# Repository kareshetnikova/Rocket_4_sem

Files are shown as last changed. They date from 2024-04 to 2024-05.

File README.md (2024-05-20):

# Физтех.Ship
Ссылка на телеграм канал - https://t.me/phystechShip, там есть все фото и видео

### Цель проекта

Разработка борткомпьютера с функцией измерения телеметрии и автоматическим выпуском парашюта.

### Борткомпьютер

1. Акселерометр+гироскоп+высотомер+компас - **GY-87**
3. Плата - Arduino nano/**Raspberry Pi Pico**
5. **SD-карта - модуль для arduino**
6. GPS - **NEO 7M**
7. GSM - **SIM800L**
8. Пищалка - **SFM-27/DC3-24V**
9. Система выброса парашюта - **механическая** или с использованием запала и вышибного заряда
10. Тумблер
11. Светодиоды индикации
12. Питание - **Li-Ion 16340 3.7V** 

### Распределение задач 

Диана:
1. Расчет центров масс и давления
2. Расчеты параметров обтекателя и стабилизаторов
3. Моделирование и создание обтекателя и стабилизаторов
4. Корпус для электроники
6. Система спасения (парашют + система его выпуска)

Ксюша:
1. Электроника борткомпьютера
2. Сборка

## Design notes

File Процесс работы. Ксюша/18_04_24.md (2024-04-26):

Запустила rp2040 (pico) из arduino ide. Мигает светодиодами, в порт данные выводит. 
BMP180 пока подключить не получилось. Но плата прикольная, берем

Подключала mpu по i2c. SDA, SCL = GP4, GP5. Непонятно, как их определять, на распиновке другие пины

Данные с mpu выводит корректно, главное - чтоб в коде не было LED_PIN = 13 и прочего.

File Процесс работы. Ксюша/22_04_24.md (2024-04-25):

Проверила UART на малинке, работает с 2 пар пинов с NEO7M.

GPS тройка модуль тоже работает.

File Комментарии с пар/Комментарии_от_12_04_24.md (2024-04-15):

### Комментарии от 12.04.2024

1. Можно использовать акум типа https://www.chipdip.ru/product/robiton-lp302030-3.7
2. Sim800l  питать от акума, а не от контроллера 
3. Ардуино можно заменить на rp2040 pico, у него 2 UART. Подумать об этом
4. Надо продумать крепление модулей внутри ракеты: корпус из пластика или макетка для пайки

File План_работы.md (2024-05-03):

# План работы 

### **12.04 - 19.04**

*Диана:*
1. Продумать конструкцию (то есть всю механику)
2. Продумать, как располагать модули (в том числе продумать корпус)

*Ксюша:*
1. Полностью продумать принципиальную схему (в том числе систему выпуска парашюта - транзистор, реле - и выбор МК)
2. Протестить все имеющиеся модули и принести

### **19.04 - 26.04**

 Запихнуть все в ракету, проверить работу борткомпьютера 
 
 *26.04: Просрочили, но все под контролем =)*

### **26.04 - 3.05**

Доработка, отладка 

### **3.05 - 10.05**

Доработка, отладка 

### **10.05 - 17.05**

1. Запуск
2. Презентация

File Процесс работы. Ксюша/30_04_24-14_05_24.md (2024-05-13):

**За это время было сделано следующее:**

1. Был добавлен отдельный акум для GSM

2. Был практически дописан код. С GSM после отправки одной смс весь БК может виснуть (иногда он умудряется отправлять больше,
но при этом данные на SD писаться перестают). Без GSM все рабоатает!! Возможное решение проблемы: добавить стабилизатор напряжения 
к акуму для GSM

3. Была сделана световая индикация работы борткомпа с помощью двух светодиодов

4. Было решено использовать два джампера для запуска борткомпа: один - для GSM, второй для всего остального
(при использовании одного акума могут возникать проблемы в работе БК, GSM ОЧЕНЬ капризный)

5. Было решено испытывать борткомп без ракеты, только на парашюте. И с костылями в виде джамперов

6. Была протестирована пищалка - работает))

7. Было решено не делать систему выпуска парашюта - соответственно, не прогать серву

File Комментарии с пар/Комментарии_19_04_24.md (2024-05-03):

### Комментарии от 19.04.2024

1. Выпуск парашюта: резерв по времени+барометр
2. Сервопривод с резинкой, дверка в корпусе 
3. Отдельный акум для реле, если используем вышибной заряд 
4. Возможно, стоит взять 2 штуки GPS, так как антенна должна быть направлена вверх либо с заданной переодичностью отправлять координату

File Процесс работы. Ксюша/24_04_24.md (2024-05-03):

Есть у ардуино нано особенность - на UART (пины 0 и 1) не должно быть ничего подключено во время прошивки. Про это надо помнить.

Подключала SIM800l:

1. С помощью блока питания из лабы
2. С помощью одной банки 18650

Мигает красный огонек 7-10 раз с частотой 1Гц, потом перерыв 3-4 с, потом снова мигает. На форумах пишут, это значит, что это проблемы с питанием.

Требования на след запуск: 

1. 4.1В/2А нужно для модуля
2. Для теста питания подходит одна банка 18650, запаянная напрямую (на макетке очень не очень работает)
3. Обязательно нужно ставить делитель напряжения на RX линию sim800l
4. У модуля должна быть общая земля с контроллером
5. Модуль очень капризный к току, так что если что-то не так в контакте, он будет сбрасываться
6. Надо попробовать две банки и стабилизатор и еще раз блок питания с симкой
7. Возможно, надо менять местами RX и TX, китайцы иногда путают

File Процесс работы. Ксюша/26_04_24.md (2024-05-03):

Удалось добиться ответа от GSM. Я сформулировала правила работы с ним, чтоб он не капризничал:

1. Вся земля вместе: от ардуины и от модуля 
2. Питание от банки 18650
3. Максимально паяем, где можно
4. Делитель на tx контроллера (на pico ставила 2 и 10 кОм)
5. Используемые пины pico - 0 и 1
6. Сначала отправляем AT, затем устанавливаем текстовый формат AT+CMGF=1, только затем отправляем сообщение

Не получается отправлять сообщения из порта. Там надо использовать char(26), непонятно, как это делать.

Подключила вместе GPS, GSM, MPU, BMP. BMP, GSM работают, GPS еще нет, надо на улицу. Не хватает SD карты, сервы для парашюта и пищалки.

Заставила GSM отправлять координаты!!! 

Посчитала, что GPS для запуска (холодный старт вроде) нужно около минуты, с запасом лучше брать 80с.

Написала код для вывода данных с GPS, MPU, BMP в порт (когда модуль SD будет - все эти данные будут выводиться туда)
и отправки координаты через заданное время после запуска контроллера. Все прошивается работает =)

Надо добавить светодиоды для индикации и предусмотреть это в корпусе.

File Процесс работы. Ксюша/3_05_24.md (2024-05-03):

Подключила SD карту вместе с остальными спаянными компонентами, работает.

Припаяла модуль SD карты.

В коде нужно сначала настроить GSM, потом делать все остальное - GSM может сильно мешать работе контроллера, если не нашел сеть. Например, он тормозит работу порта.

Питание от акума с VSYS (1.8-5.5В на входе), GSM параллельно.

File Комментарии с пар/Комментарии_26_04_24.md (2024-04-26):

Электроника по большей части и корпус должны быть готовы к 3.05.2024, весь проект - к 10.05.2024

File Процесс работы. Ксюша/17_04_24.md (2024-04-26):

Подключала молуль SD-карты. Пробовала 2 рабочие платы ардуино нано. Подключение: sck-->13, mosi-->11, miso-->12, cs-->10. Несколько разных скетчей пробовала.
Две разных SD. В порту ошибка инициализации.

BMP180, MPU6050 вертикальный работают (в том числе вместе). Горизонтальный не работает.
Работают две ардуины с желтым скотчем на разъеме.

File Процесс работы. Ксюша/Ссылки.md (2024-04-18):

Сбор данных с bmp180 и mpu6050 на SD карту: https://github.com/Xavi009/mpu6050_bmp180_arduino

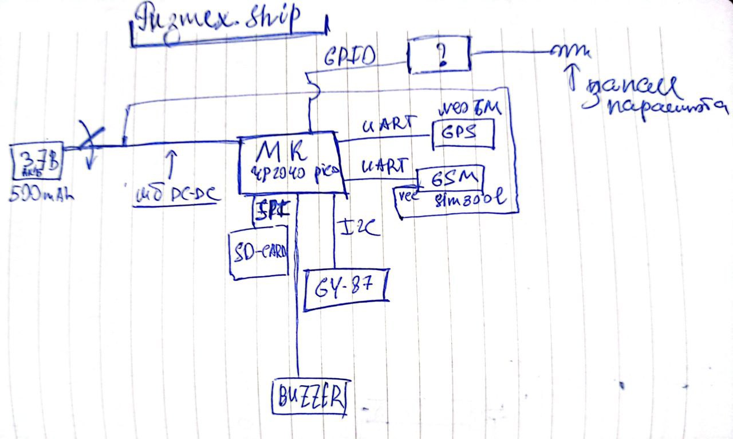
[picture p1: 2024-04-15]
Материалы (схемы, 3D модели и прочее)/Схема_борткомпьютера.jpg

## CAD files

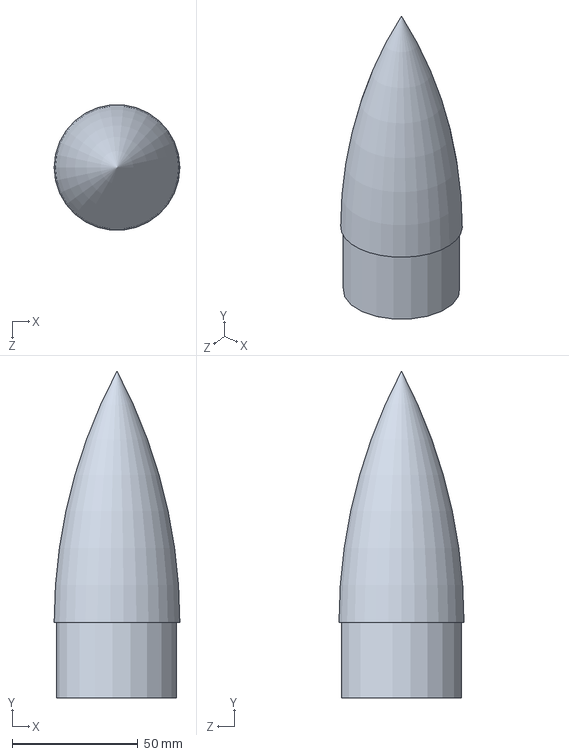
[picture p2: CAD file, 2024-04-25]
Материалы (схемы, 3D модели и прочее)/обтекатель.SLDPRT
50.0 x 130.0 x 49.7 mm

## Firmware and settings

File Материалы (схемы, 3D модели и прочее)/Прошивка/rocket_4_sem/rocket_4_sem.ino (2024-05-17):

#include <TinyGPSPlus.h>
#include <SoftwareSerial.h>
#include "I2Cdev.h"
#include "MPU6050.h"
#include <Adafruit_BMP085.h>
#include <SPI.h>
#include <SD.h>
#include "math.h"


float g = 9.8155;
float R = 8.3145;
float mu = 0.002898;

static const int PIN_CHIP_SELECT = 17;
static const int GPSrx = 9, GPStx = 8, GSMrx = 1, GSMtx = 0;
static const int RED_LED_PIN = 21;
static const int GREEN_LED_PIN = 20;
static const int BUZZER_PIN = 22;

static const uint32_t GPSBaud = 9600;
static const uint32_t SerialBaud = 9600;
static const uint32_t GSMBaud = 9600;
int16_t ax, ay, az;
int16_t gx, gy, gz;
String responseAT = "";  // для хранения ответа от GSM
String _response;
String responseTextMode = ""; 
bool flagGSM = 1; // флаг для отправки сообщений о координатах 
bool FlagGreenLed;
bool FlagRedLed;
bool flagLastSMS = 1;
bool flagHmax = false;
bool flagSentHmax = false;
bool flagMillis = true;

char sms[300];
char sd[300];
char maxHsms[50];
int decLat;
int intLat;
int intLng;
int decLng;
int decT;
int intT;
int P0, p, p1, p2, p3;
float T1, T2, T3;
int intHmax, decHmax;
int timerP1, timerP2, timerP3;



// Настройки работы БК
int CntSMS = 0;
int TotalNumberSMS = 5;
int timerSendCoord;
int PeriodSMS = 1000;
int timeWorkBK = 40000;
int PeriodWriteSD = 100;
int PeriodBuzzer = 1000;
int frequencyBuzzer = 1500;
int timeBuzzer = 1000;



TinyGPSPlus gps;
MPU6050 accelgyro;
Adafruit_BMP085 bmp;

SoftwareSerial ss(GPSrx, GPStx);
SoftwareSerial SIM800(GSMrx, GSMtx);        

int TimeStartGPS;
int timeDisplayInfo;
int TimeGSM;
int timeSD;
int timeStopSD;
int timeRedLed;
int timeGreenLed;
int timeStartGSM;
int timeSendLastCoord;
int timerBuzzer;

void setup() {
  Serial.begin(SerialBaud);
  //while(!Serial);
  
  Wire.begin();

  // свеодиоды
  pinMode(RED_LED_PIN, OUTPUT);  
  pinMode(GREEN_LED_PIN, OUTPUT);  


  //sim800l
  /*timeRedLed = millis();
  FlagRedLed = false;
  SIM800.begin(GSMBaud);
  
  while(SIM800.available() <= 0)
  {
    if (millis() - timeRedLed >= 500)
    {
      Serial.println("Нет подключения к SIM800l");
      digitalWrite(RED_LED_PIN, FlagRedLed);
      digitalWrite(GREEN_LED_PIN, !FlagRedLed); 
      timeRedLed = millis();
      FlagRedLed = !FlagRedLed;
    }
  }*/  
  
  SIM800.begin(GSMBaud);
  
  //ждем 15 сек, чтоб gsm заработал
  int timerStartBK = millis();
  while(millis() - timerStartBK <= 5000)
  {;}      

  responseAT = sendATCommand("AT", true);  
  responseAT.trim();                       // Убираем пробельные символы в начале и конце

  responseTextMode = sendATCommand("AT+CMGF=1;&W", true); // Включаем текстовый режима SMS (Text mode) и сразу сохраняем значение (AT&W)!
  responseTextMode.trim();

   sendSMS("+79646360100", "GSM is connected");

  /*
  // Если GSM отвечает, мигаем в течение 5 с зеленым светодиодом раз в 500мс. Иначе красным и зеленым
  timeRedLed = millis();
  FlagRedLed = false;
  do {
    responseAT = sendATCommand("AT", true);  
    responseAT.trim();                       // Убираем пробельные символы в начале и конце

    responseTextMode = sendATCommand("AT+CMGF=1;&W", true); // Включаем текстовый режима SMS (Text mode) и сразу сохраняем значение (AT&W)!
    responseTextMode.trim();
    
    if (millis() - timeRedLed >= 200)
    {
      Serial.println("Нет подключения к SIM800l");
      Serial.print("Ответ GSM (AT, TextMode): ");
      Serial.print(responseAT);
      Serial.println(responseTextMode);
      digitalWrite(RED_LED_PIN, FlagRedLed);
      digitalWrite(GREEN_LED_PIN, !FlagRedLed); 
      timeRedLed = millis();
      FlagRedLed = !FlagRedLed;
    }
    
  } while (responseAT != "OK" && responseTextMode != "OK");              // Не пускать дальше, пока модем не вернет ОК
  
  Serial.print("Ответ GSM (AT, TextMode): ");
  Serial.print(responseAT);
  Serial.println(responseTextMode);

  digitalWrite(RED_LED_PIN, false);
  digitalWrite(GREEN_LED_PIN, false);

  
 
    if (responseAT == "OK" && responseTextMode == "OK")
    {
       timeGreenLed = millis();
       timeStartGSM = millis();
       FlagGreenLed = false;
      Serial.println("SIM800l работает");
      while(millis() - timeStartGSM <= 3000)
      {
        if (millis() - timeGreenLed >= 300)
        {
          digitalWrite(GREEN_LED_PIN, FlagGreenLed); 
          timeGreenLed = millis();
          FlagGreenLed = !FlagGreenLed;
        }
        
      } 

    }

digitalWrite(RED_LED_PIN, false);
digitalWrite(GREEN_LED_PIN, false);
 */   
  
  

 /* else 
  {
    timeRedLed = millis();
    FlagRedLed = false;
    SIM800.begin(GSMBaud);

    while(1)
    {
      if (millis() - timeRedLed >= 500)
      {
        Serial.println("Нет подключения к SIM800l");
        digitalWrite(RED_LED_PIN, FlagRedLed);
        digitalWrite(GREEN_LED_PIN, !FlagRedLed); 
        timeRedLed = millis();
        FlagRedLed = !FlagRedLed;
      } 
  
    }
  }*/

  

  // initialize bmp085
  timeRedLed = millis();
   FlagRedLed = false;
  // мигаем красным светодиодом раз в 1с
  while(!bmp.begin())
  {
    if (millis() - timeRedLed >= 1000)
    {
      Serial.println("Нет подключения к BMP");
      digitalWrite(RED_LED_PIN, FlagRedLed); 
      timeRedLed = millis();
      FlagRedLed = !FlagRedLed;
    }
  }
    
  digitalWrite(RED_LED_PIN, false);
  digitalWrite(GREEN_LED_PIN, false);
  
  // initialize mpu6050
  accelgyro.initialize();   
   timeRedLed = millis();
   FlagRedLed = false;
  // мигаем красным светодиодом раз в 0.5с
  while(!accelgyro.testConnection())
  {
    if (millis() - timeRedLed >= 500)
    {
      Serial.println("Нет подключения к MPU");
      digitalWrite(RED_LED_PIN, FlagRedLed); 
      timeRedLed = millis();
      FlagRedLed = !FlagRedLed;
    }
  }
  
  digitalWrite(RED_LED_PIN, false);
  digitalWrite(GREEN_LED_PIN, false);

 // initialize SD
  timeRedLed = millis();
  FlagRedLed = false;
 // Этот пин обязательно должен быть определен как OUTPUT
  pinMode(PIN_CHIP_SELECT, OUTPUT); 
  // мигаем красным светодиодом раз в 3с
  while(!SD.begin(PIN_CHIP_SELECT))
  {
    if (millis() - timeRedLed >= 3000)
    {
      Serial.println("Нет подключения к SD");
      digitalWrite(RED_LED_PIN, FlagRedLed); 
      timeRedLed = millis();
      FlagRedLed = !FlagRedLed;
    }
  }
    
   digitalWrite(RED_LED_PIN, false);
  digitalWrite(GREEN_LED_PIN, false); 


 // initialize GPS    
  
 ss.begin(GPSBaud);
    
  
 timeRedLed = millis();
 FlagRedLed = false;
 while(ss.available() <= 0 || !gps.encode(ss.read()) || !gps.location.isValid())
{
  if (millis() - timeRedLed >= 500)
  {
    Serial.println("Нет подключения к GPS");
    digitalWrite(RED_LED_PIN, FlagRedLed);
    digitalWrite(GREEN_LED_PIN, FlagRedLed); 
    timeRedLed = millis();
    FlagRedLed = !FlagRedLed;
  } 
}



digitalWrite(RED_LED_PIN, false);
digitalWrite(GREEN_LED_PIN, false);

  
  int timerReadyBK = millis();
  timeGreenLed = millis();
  timeStartGSM = millis();
  FlagGreenLed = false;
  Serial.println("Все работает");
  while(millis() - timerReadyBK <= 10000)
  {
    if (millis() - timeGreenLed >= 1000)
    {
      digitalWrite(GREEN_LED_PIN, FlagGreenLed); 
      timeGreenLed = millis();
      FlagGreenLed = !FlagGreenLed;
    }
  }    

   //начальное давлние
   P0 = bmp.readPressure();

  TimeStartGPS = millis();
  timeDisplayInfo = millis();
  TimeGSM = millis();
  timeSD = millis();
  timerSendCoord =  millis();
  timeSendLastCoord =  millis();
  timerBuzzer = millis();
  timerP1 = millis();
  timerP2 = millis();
  timerP3 = millis();

  digitalWrite(RED_LED_PIN, false);
  digitalWrite(GREEN_LED_PIN, false);

 

}


void loop() {

  if (flagMillis == 1)
  {
    timeStopSD = millis();
    flagMillis = 0;
    
  }

while(ss.available() > 0)
  gps.encode(ss.read());

/*
// ОТЛАДКА РАБОТЫ GSM

  if (SIM800.available())   {                   // Если модем, что-то отправил...
    _response = waitResponse();                 // Получаем ответ от модема для анализа
    _response.trim();                           // Убираем лишние пробелы в начале и конце
    Serial.println(_response);                  // Если нужно выводим в монитор порта
    //....
    if (_response.startsWith("+CMGS:")) {       // Пришло сообщение об отправке SMS
      int index = _response.lastIndexOf("\r\n");// Находим последний перенос строки, перед статусом
      String result = _response.substring(index + 2, _response.length()); // Получаем статус
      result.trim();                            // Убираем пробельные символы в начале/конце

      if (result == "OK") {                     // Если результат ОК - все нормально
        Serial.println ("Message was sent. OK");
      }
      else {                                    // Если нет, нужно повторить отправку
        Serial.println ("Message was not sent. Error");
      }
    }
  }
  if (Serial.available())  {                    // Ожидаем команды по Serial...
    SIM800.write(Serial.read());                // ...и отправляем полученную команду модему
  };



  

// TotalNumberSMS - количество смс, отправленных с периодичностью 1000 мс
  if (millis() - timerSendCoord >= PeriodSMS && CntSMS < TotalNumberSMS)
  {
    //отправляем смс   
    if (gps.location.isValid() && gps.time.isValid())
    {
      if (flagHmax == true && flagSentHmax == false)
      {
        splitFloat(gps.location.lat(), 6, intLat, decLat);
        splitFloat(gps.location.lng(), 6, intLng, decLng);
        sprintf(sms, "lat = %d.%d lng = %d.%d time = %d:%d:%d.%d Hmax = %d.%d m", intLat, decLat, intLng, decLng, gps.time.hour(), gps.time.minute(), 
        gps.time.second(), gps.time.centisecond(), intHmax, decHmax);
        sendSMS("+79646360100", sms);
        flagSentHmax = true;
      }
      else
      {
        splitFloat(gps.location.lat(), 6, intLat, decLat);
        splitFloat(gps.location.lng(), 6, intLng, decLng);
        sprintf(sms, "lat = %d.%d lng = %d.%d time = %d:%d:%d.%d", intLat, decLat, intLng, decLng, gps.time.hour(), gps.time.minute(), gps.time.second(), gps.time.centisecond());
        sendSMS("+79646360100", sms);
      }
    }
    else
    {
      sendSMS("+79646360100", "INVALID");
    }

    CntSMS = CntSMS + 1;
    timerSendCoord = millis();
  }
*/

  //Отправляем одну смс, чтоб нашли борткомп
  if (millis() - timeSendLastCoord >= 40000 && flagLastSMS == 1)
  {
    //отправляем смс   
    if (gps.location.isValid() && gps.time.isValid())
    {
      splitFloat(gps.location.lat(), 6, intLat, decLat);
      splitFloat(gps.location.lng(), 6, intLng, decLng);
      sprintf(sms, "last coord: lat = %d.%d lng = %d.%d time = %d:%d:%d.%d", intLat, decLat, intLng, decLng, gps.time.hour(), gps.time.minute(), gps.time.second(), gps.time.centisecond());
      sendSMS("+79646360100", sms);
    }
    else
    {
      sendSMS("+79646360100", "INVALID");
    }

    flagLastSMS = 0;
  }


// ПИЩАЛКА

if (millis() - timeSendLastCoord >= 40000 && millis() - timerBuzzer >=  PeriodBuzzer)
{
   tone(BUZZER_PIN, frequencyBuzzer, timeBuzzer);
   timerBuzzer = millis();
}


/*
  // ОТПРАВКА СМС НА МАКСИМАЛЬНОЙ ВЫСОТЕ
  if (millis() - timerP1 >= 60)
  {
    T1 = bmp.readTemperature();
    for (int i=0; i<10; i++)
    {
    p = bmp.readPressure();
    p1 = p1 + p;
    }
    timerP1 = millis();
  }

  if (millis() - timerP2 >= 80)
  {
    T2 = bmp.readTemperature();
    for (int i=0; i<10; i++)
    {
    p = bmp.readPressure();
    p2 = p2 + p;
    }
    timerP2 = millis();
  }

   if (millis() - timerP3 >= 100)
  {
    T3 = bmp.readTemperature();
    for (int i=0; i<10; i++)
    {
    p = bmp.readPressure();
    p3 = p3 + p;
    }
    timerP3 = millis();
  }
 
  
  if (p2>p1 && p3>p2)
  {
     int P1 = p1/10;
     float Hmax = log (P0/P1)*R*T1/mu/g;
     splitFloat(Hmax, 2, intHmax, decHmax);   
     flagHmax = true;
  }
    
    
*/



  // SD КАРТА

  if (millis() - timeStopSD <= timeWorkBK && millis() - timeSD >= PeriodWriteSD)
  {
      // Если файла с таким именем не будет, ардуино создаст его.
    File dataFile = SD.open("DATA_last.csv", FILE_WRITE);
  
    accelgyro.getMotion6(&ax, &ay, &az, &gx, &gy, &gz);
    splitFloat(bmp.readTemperature(), 1, intT, decT);
    int P = bmp.readPressure();

    // запись координаты 
    if (gps.location.isValid() && gps.time.isValid())
    {
      splitFloat(gps.location.lat(), 6, intLat, decLat);
      splitFloat(gps.location.lng(), 6, intLng, decLng);
      sprintf(sd, "%d.%d\t%d.%d\t%d:%d:%d.%d\t%d\t%d\t%d\t%d\t%d\t%d\t%d\t%d.%d", intLat, decLat, intLng, decLng, gps.time.hour(), 
              gps.time.minute(), gps.time.second(), gps.time.centisecond(), ax, ay, az, gx, gy, gz, P, intT, decT);
      
    }
    else
    {sprintf(sd, "INVAILD \t INVAILD \t INVAILD \t%d\t%d\t%d\t%d\t%d\t%d\t%d%d.%d", ax, ay, az, gx, gy, gz, P, intT, decT);
    }
     
    
    // Если все хорошо, то записываем строку:
    if (dataFile) {
      dataFile.println(sd);
      dataFile.close();
      // Публикуем в мониторе порта для отладки
      Serial.print("SD: ");
      Serial.println(sd);
    }
    else {
    // Сообщаем об ошибке, если все плохо
      Serial.println("error opening datalog.csv");
    }

    timeSD = millis();    
  }
  
  
}


void splitFloat(float num, int precision, int &integerPart, int &decimalPart) {
  integerPart = int(num);
  float remainder = num - integerPart;
  decimalPart = int(remainder * pow(10, precision)); // Добавлено 0.5 для корректного округления
  
}


void displayInfo()
{
  // вывод координат
  if (gps.location.isValid())
  {
    // МИГАЕМ ЗЕЛЕНЫМ СВЕТОДИОДОМ, ДАННЫЕ ВСЕ БУДУТ
    Serial.print(gps.location.lat(), 6);
    Serial.print(F("\t"));
    Serial.print(gps.location.lng(), 6);
  }
  else
  {
    Serial.print(F("INVALID"));
  }

  //вывыод даты и времени
  Serial.print(F("\t"));
  if (gps.date.isValid())
  {
    Serial.print(gps.date.month());
    Serial.print(F("/"));
    Serial.print(gps.date.day());
    Serial.print(F("/"));
    Serial.print(gps.date.year());
  }
  else
  {
    Serial.print(F("INVALID"));
  }

  Serial.print(F("\t"));
  if (gps.time.isValid())
  {
    if (gps.time.hour() < 10) Serial.print(F("0"));
    Serial.print(gps.time.hour());
    Serial.print(F(":"));
    if (gps.time.minute() < 10) Serial.print(F("0"));
    Serial.print(gps.time.minute());
    Serial.print(F(":"));
    if (gps.time.second() < 10) Serial.print(F("0"));
    Serial.print(gps.time.second());
    Serial.print(F("."));
    if (gps.time.centisecond() < 10) Serial.print(F("0"));
    Serial.print(gps.time.centisecond());
  }
  else
  {
    Serial.print(F("INVALID"));
  }



  // температура в *С и давление в Па
  Serial.print(F("\t"));
  Serial.print(bmp.readTemperature());
  Serial.print(F("\t"));
  Serial.print(bmp.readPressure());

  // данные с MPU
  Serial.print(F("\t"));
  accelgyro.getMotion6(&ax, &ay, &az, &gx, &gy, &gz);
  Serial.print(ax); Serial.print("\t");
  Serial.print(ay); Serial.print("\t");
  Serial.print(az); Serial.print("\t");
  Serial.print(gx); Serial.print("\t");
  Serial.print(gy); Serial.print("\t");
  Serial.println(gz);

  }



  String sendATCommand(String cmd, bool waiting) {
  String _resp = "";                            // Переменная для хранения результата
  Serial.println(cmd);                          // Дублируем команду в монитор порта
  SIM800.println(cmd);                          // Отправляем команду модулю
  if (waiting) {                                // Если необходимо дождаться ответа...
    _resp = waitResponse();                     // ... ждем, когда будет передан ответ
    // Если Echo Mode выключен (ATE0), то эти 3 строки можно закомментировать
    if (_resp.startsWith(cmd)) {  // Убираем из ответа дублирующуюся команду
     _resp = _resp.substring(_resp.indexOf("\r", cmd.length()) + 2);
    }
    Serial.println(_resp);                      // Дублируем ответ в монитор порта
  }
  return _resp;                                 // Возвращаем результат. Пусто, если проблема
}

String waitResponse() {                         // Функция ожидания ответа и возврата полученного результата
  String _resp = "";                            // Переменная для хранения результата
  long _timeout = millis() + 10000;             // Переменная для отслеживания таймаута (10 секунд)
  while (!SIM800.available() && millis() < _timeout)  {}; // Ждем ответа 10 секунд, если пришел ответ или наступил таймаут, то...
  if (SIM800.available()) {                     // Если есть, что считывать...
    _resp = SIM800.readString();                // ... считываем и запоминаем
  }
  else {                                        // Если пришел таймаут, то...
    Serial.println("Timeout...");               // ... оповещаем об этом и...
    _resp = "no answer";
  }
  return _resp;                                 // ... возвращаем результат. Пусто, если проблема
}


void sendSMS(String phone, String message)
{
  sendATCommand("AT+CMGS=\"" + phone + "\"", true);             // Переходим в режим ввода текстового сообщения
  sendATCommand(message + "\r\n" + (String)((char)26), true);   // После текста отправляем перенос строки и Ctrl+Z
}

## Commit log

2024-04-18 обтекатель
    [обтекатель.SLDPRT]
2024-04-30 Add files via upload
    каркас для борткомпьютера, расчитан на диаметр 50 мм, в длину получается 115 мм, надо добавить еще отверстия для индикаторов и кнопки
2024-05-01 доделанные слегка
2024-05-01 Add files via upload
    корпус, верхняя и нижняя крышка + сборка со всеми деталями в их размерах
2024-05-01 в формате STL
    [коробка.stl, коробка2.stl]
2024-05-10 обновленные модели корпуса
